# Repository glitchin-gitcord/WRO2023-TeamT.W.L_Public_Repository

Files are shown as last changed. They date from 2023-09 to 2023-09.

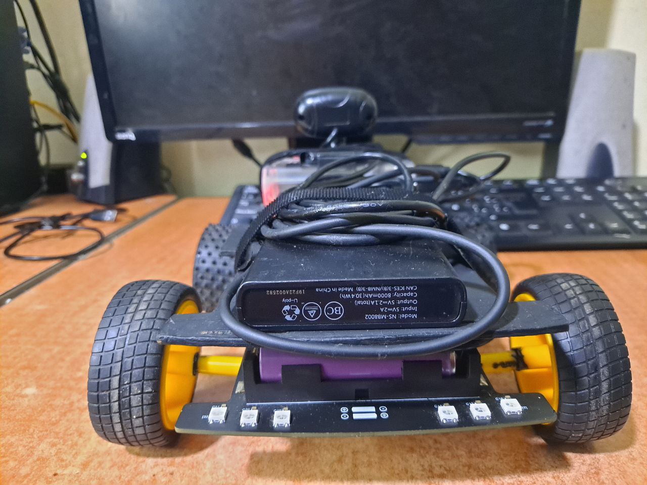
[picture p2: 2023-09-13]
v-photos/back part.jpeg

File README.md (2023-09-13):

Engineering materials
====

This repository contains engineering materials of a self-driven vehicle's model participating in the WRO Future Engineers competition in the season 2023 (Team T.W.L).

## Content

* `t-photos` contains 2 photos of the team (an official one and one funny photo with all team members)
* `v-photos` contains 6 photos of the vehicle (from every side, from top and bottom)
* `video` contains the video.md file with the link to a video where driving demonstration exists
* `schemes` contains one or several schematic diagrams in form of JPEG, PNG or PDF of the electromechanical components illustrating all the elements (electronic components and motors) used in the vehicle and how they connect to each other.
* `src` contains code of control software for all components which were programmed to participate in the competition
* `models` is for the files for models used by 3D printers, laser cutting machines and CNC machines to produce the vehicle elements. If there is nothing to add to this location, the directory can be removed.
* `other` is for other files which can be used to understand how to prepare the vehicle for the competition. It may include documentation how to connect to a SBC/SBM and upload files there, datasets, hardware specifications, communication protocols descriptions etc. If there is nothing to add to this location, the directory can be removed.

## Introduction

_Hello, Here Luis from Team T.W.L., and again I and my colleagues will expand a little in the operational elements present in the robotic solution for this 2023 season._

-------------------------------------------------------------------------------------------------------------------------------------  

_The designed robotic solution model this time consists on a modification of the original robot car we built, leaving only some parts for ease and costs savings. Again, this robot car is powered by ESP-32 and Raspberry Pi 4 and programmed in C++ (ARDUINO IDE) and Python._

_Now, we will expand in the main aspects used and incluided in the robot car's development (**Elements** and **Coding Environments**):_

     Elements

  -   _Motors: The robot has 1 direct current (DC) motor and 1 SG90 servomotor that allow it to move in different directions. Meanwhile the DC motor serves as rear wheel drive, the servomotor gives it the ability to turn left or right. The rear wheel drive motor provides the forward or backward motion of the robot, while the turning motor rotates the front wheels to change the orientation of the robot. By combining these two motions, the robot can move in any direction on a flat surface._  

  -   _ESP-32: Dual-Core SoC Chip (System on a Chip) of low cost and energy that uses a Tensilica Xtensa LX6 microprocessor (both in the one used here, and in its single or dual-core variants). Being an popular alternative to use beacuse of the low energy compsuntion and high processing power. This, along with the Raspberry Pi, being the main elements in the entire robot._

  -   _Raspberry Pi 4: The Raspberry Pi 4 is a single-board development board used for entry-level computing, being released the latest version (Raspberry Pi 4) in June 2019. The board is available in four RAM variants: 1 GB, 2 GB, 4 GB, and 8 GB. Model B (the one we are using) is the most common and comes with a Broadcom BCM2711 processor, which is a 1.5GHz quad-core ARM Cortex-A72 processor. Additionally, it has enhanced USB capability with two USB 2.0 ports and two USB 3.0 ports, enabling up to ten times faster data transfers. It also comes with Gigabit Ethernet connectivity, built-in wireless and Bluetooth._

  _Before, the ESP-32 did all the hard work in the entire robot, but in the tests we noticed that it wouldn't take it, so we looked for alternatives to something that could take all the functions the robot had to handle by itself, so Edilio had the idea to use a Raspberry Pi 4 because of the experience he had investigating about it, so we got one to take at least the camera and color recognition functions, leaving the rest to the ESP-32._

   -   _Ultrasonic board: The robot has an HC-SR04 ultrasonic board that works as a sonar. The HC-SR04 sensor has two transducers: a piezoelectric transmitter and receiver, in addition to the electronics necessary for its operation. The operation of the sensor is as follows: the piezoelectric transmitter emits 8 ultrasonic pulses (40KHz) after receiving the order on the TRIG pin, the sound waves travel in the air and bounce when meeting an object, the bounce sound is detected by the piezoelectric receiver, then the ECHO pin changes to High (5V) for a time equal to the time the wave took from when it was emitted to when it was detected, the time of the ECHO pulse is measured by the microcontroller and thus the distance can be calculated to the object. Sensor performance is not affected by sunlight or black-colored material (although acoustically soft materials such as cloth or wool can be difficult to detect). All of this in a range of 2 to 450 cm._

   -   _Camera: The robot uses an Argom Tech 720p Cam20 Webcam, pretty generic so I can't really expand in detail about it._  

   -   _Power Supply Elements:_
   
   =   _3.7V 18650 Lithium Batteries: The robot, due to its high energy consumption (yeh, still uses a lot of energy) uses this peculiar type of batteries to supply itself with energy. These batteries are rechargeable and have a capacity of between 1500 and 3500 mAh (ours supposedly have 9900 mAh but I highly doubt it). The batteries have a nominal voltage of 3.7V and a maximum voltage of 4.2V. The batteries are connected to the robot through a battery holder that has an on/off switch. The batteries can be charged with a special charger that has a protection circuit against overloads and short circuits._

   =   _Power Bank: Because some SBC didn't want to use the same batteries that everyone else used, here we are. Seriously speaking, for accesibility reasons mostly, we use a Insignia NS-MB8002 Power Bank to supply the Raspberry Pi with energy. It has 2 USB ports, along with a Micro-USB port for charging, with an output voltage of 5V and 2.1A._

    Coding Environments
_The previous time we didn't really expand in this point, but although it is not relevant in which programming environment you're developing this, it is relevant to clarify what the ARDUINO IDE is and why we use it in the development of the robot._

  -   _ARDUINO Integrated Development Environment (C++): The Arduino Integrated Development Environment (IDE) is a cross-platform software (for Windows, macOS, Linux) written in the Java programming language. It is used to write and upload code to Arduino-compatible boards, as well as other boards from different manufacturers with the help of additional cores._

_It can handle C and C++ languages with specific rules for organizing the code. It also provides a software library from the Wiring project that has many common I/O functions. The code written by users only needs two basic functions: one to start the sketch and one to run the main loop. These functions are compiled and linked with a main() function in a loop using the GNU toolchain, which is also part of the IDE. The Arduino IDE uses a program called avrdude to turn the executable code into a text file with hexadecimal encoding that is transferred to the Arduino board by a loader program in the board’s firmware._

Its function related to code would be to control movements (rear wheel drive, turn left or right), based on the information sent by the camera (more info ahead).

  -   _Python: Python Integrated Development Environment (or Python for short) is a high-level interpreted programming language whose philosophy emphasizes the readability of its code, it is used to develop applications of all kinds, for example: Instagram, Netflix, Spotify, Panda3D, among others. It is a multi-paradigm programming language, since it partially supports object orientation, imperative programming and, to a lesser extent, functional programming. It is an interpreted, dynamic and cross-platform language. Created back in late 80s, Python consistently ranks as one of the most popular programming languages._

Its function related to code would be to detect colors and control the camera, and, subsequently, sends orders to the ESP-32 to move based on that information.

-----------------------------------------------------------------------------------------------------------------------------------------

    HOW THE CAMERA WORKS

_The artificial vision algorithms that are used to recognize objects or colors are computer programs that process the images captured by the camera and extract relevant information from them. For example, to recognize colors, We use an algorithm that converts color images to grayscale and then applies a red, green or blue color mask depending on the color we want to detect. Then, we calculate the percentage of pixels of the desired color in the image and compare it with a predefined threshold to determine whether or not there is presence of the color._

    HOW TO COMPILE THE CODE TO THE VEHICLE

_If you already finished the code that you are going to enter to ESP-32, the process of compiling it would be the following:_
- _Connect the ESP-32 to the computer through a Micro-USB cable_
- _Look for the button in the Programming Environment to transfer the code_
- _Wait for it to finish_

  {and well, Python runs natively on the Raspberry Pi, so}

--------------------------------------------------------------------------------------------------------------------------------------

    OBJECTIVE OF THE ROBOTIC SOLUTION.

The objetctive of this robotic solution is to demonstrate the capabilities of a study field such as robotics, kids and adults alike {well, we should serve as enough example to prove that concept ¯\_(ツ)_/¯}.

--------------------------------------------------------------------------------------------------------------------------------------
_Thank You._
======================================================================================================================================

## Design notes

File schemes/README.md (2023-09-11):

Electromechanical diagrams
====

This directory must contain one or several schematic diagrams in form of JPEG, PNG or PDF of the electromechanical components illustrating all the elements (electronic components and motors) used in the vehicle and how they connect to each other.

-------

Hi, Luis here, to quickly clarify what is connected to what:

- The car reads the voltage of the batteries through GPIO32 of ESP32. Because the battery 
voltage is not read frequently, this GPIO is also used to control the WS2812 LED.

The voltage acquisition range of GPIO32 on ESP32 is 0-3.3V, while the car is powered by two 18650 lithium 
batteries, whose voltage is 8.4V when they are fully charged, which exceeds the acquisition range of ESP32. 
Therefore, after passing through the voltage divider circuit composed of R3 and R4, the voltage at A0/WS2812 
will be about 1/4 of the battery voltage, 8.4/4=2.1V, which is within the voltage collection range of GPIO32.

- As can be seen from the figures "Ultrasonic" and "Esp-32", ESP32 uses GPIO12 and GPIO15 to control the 
"Trig" and "Echo" pins of the ultrasonic module.

- About the motors, As can be seen from the figure "motor controller", if we want to control the motor M1, we need to set the 14th and 15th 
channels of the PCA9685.

And as for the servos, channels 0-7 of PCA9685 are used to control servos.

- Although not illustrated correctly, the Raspberry Pi 4 gets its energy from a Power Bank via USB, connects to the Esp32 via USB and uses the Webcam via USB.
------------------------

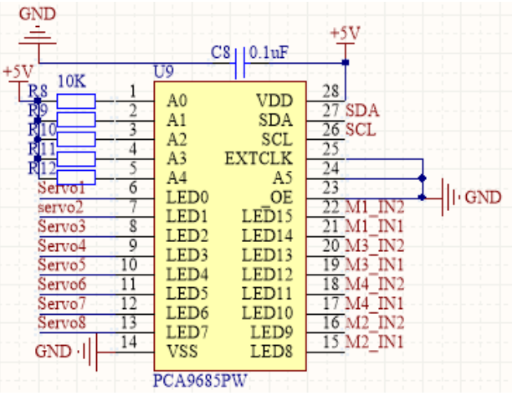
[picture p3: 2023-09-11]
schemes/motor controller.png

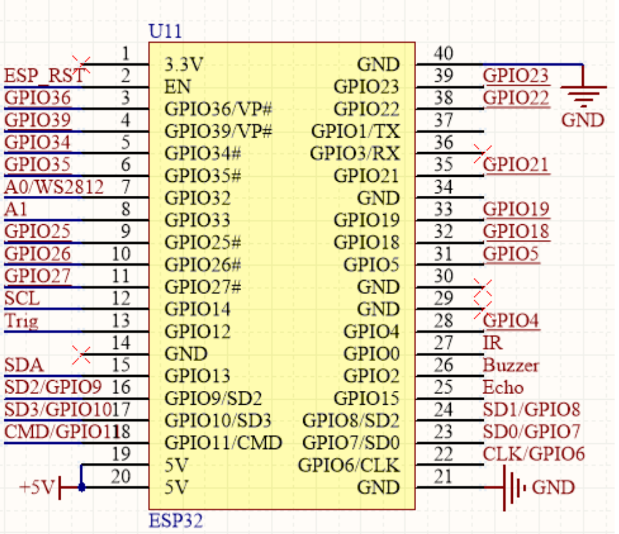
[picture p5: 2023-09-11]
schemes/Esp-32.png

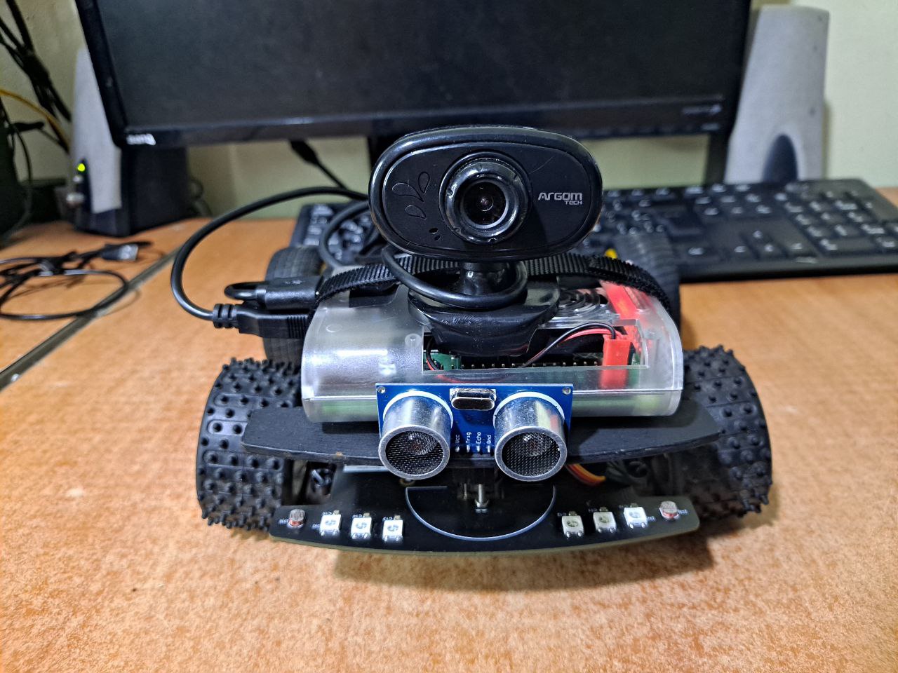
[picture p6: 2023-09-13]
v-photos/front part.jpeg

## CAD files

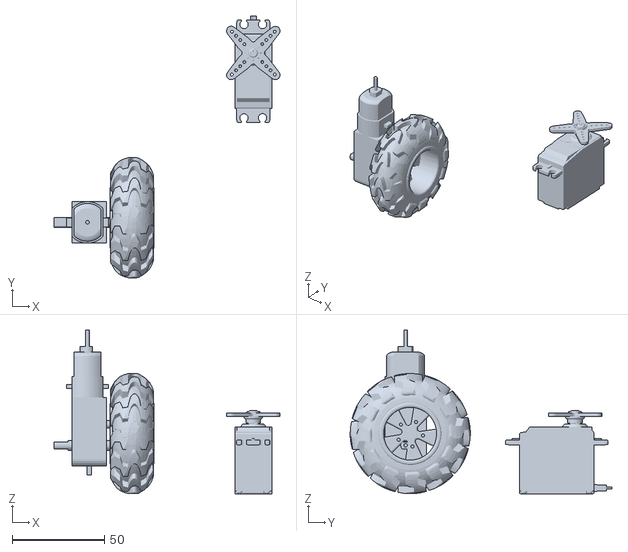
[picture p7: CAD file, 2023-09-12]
models/Copy of TT Motor and Wheel.stl
122.2 x 141.5 x 88.6

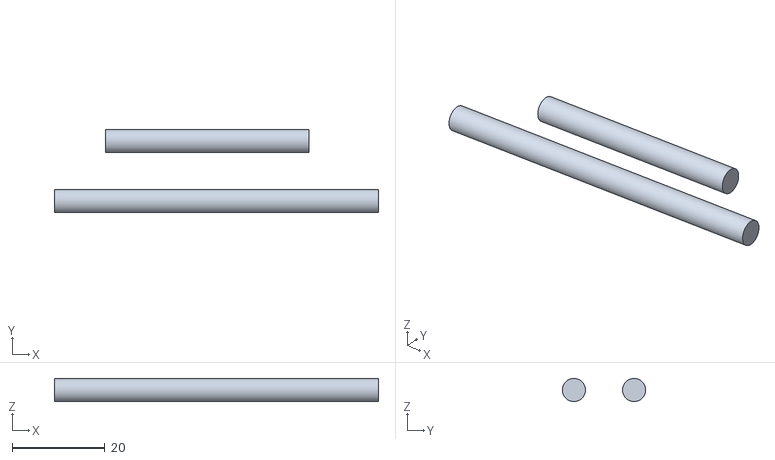
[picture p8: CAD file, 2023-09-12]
models/Magnificent Hillar.stl
70.0 x 18.0 x 5.00

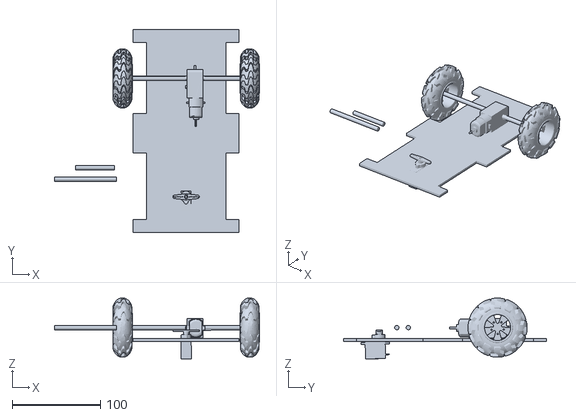
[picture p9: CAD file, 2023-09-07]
models/Swanky Snicket.stl
232.0 x 230.0 x 69.0

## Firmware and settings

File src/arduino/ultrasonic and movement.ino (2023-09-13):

#include <Arduino.h>
#include "Freenove_4WD_Car_For_ESP32.h"

#define OBSTACLE_DISTANCE      30
#define OBSTACLE_DISTANCE_LOW  15
int distance[4];     //Storage of ultrasonic data

String entradaSerial = "";
bool entradaCompleta = false;

void setup() {
  Ultrasonic_Setup();//Initialize the ultrasonic module
  PCA9685_Setup();   //PCA9685 chip initializes
  Serial.begin(115200);
  Serial.println("the bluetooth device is ready to pair");
  Servo_1_Angle(105);//Set servo 1 Angle
}

void loop()
{
  get_distance(1);//Get multiple Angle distance data
  if (distance[1] > OBSTACLE_DISTANCE)//There is no obstacle within 40cm of the front of the car
  {
    if (distance[0] >= distance[2] && distance[2] < OBSTACLE_DISTANCE_LOW) {    //There is an obstacle on the right
      Motor_Move(-1500, -1500, -1500, -1500);
      delay(1200);
      Servo_1_Angle(85);
      Motor_Move(2500, 2500, 2500, 2500);
      delay(1200);
      Servo_1_Angle(105);
    }                                   
    else if (distance[0] < distance[2] && distance[0] < OBSTACLE_DISTANCE_LOW) { //There is an obstacle on the left
      Motor_Move(-1500, -1500, -1500, -1500);
      delay(1200);
      Servo_1_Angle(85);
      Motor_Move(2500, 2500, 2500, 2500);
      delay(1200);
      Servo_1_Angle(105);                      
    }            
    else                                                                      //There are no obstacles around
      Motor_Move(2500, 2500, 2500, 2500);                                                                         
    delay(20);
  }

  else if (distance[1] < OBSTACLE_DISTANCE)  //There is an obstacle ahead
  {
    Motor_Move(0, 0, 0, 0);                  //Stop the car to judge the situation
    get_distance(2);
    if (distance[1] < OBSTACLE_DISTANCE_LOW) //The car got too close to the obstacle
    {
      Motor_Move(-1900, -1900, -1900, -1900);
      }
    else if (distance[0] < distance[2]) {     //There is also an obstacle on the left
      Motor_Move(-1500, -1500, -2000, -2000);
      delay(1200);
      Servo_1_Angle(85);
      Motor_Move(2500, 2500, 2500, 2500);
      delay(1200);
      Motor_Move(0, 0, 0, 0);
      Servo_1_Angle(105); 
      delay(250);         
    }
    else if (distance[0] > distance[2]) {     //There is also an obstacle on the right
     Motor_Move(-1500, -1500, -2000, -2000);
     delay(1200);
     Servo_1_Angle(85);
     Motor_Move(2500, 2500, 2500, 2500);
     delay(1200);
     Motor_Move(0, 0, 0, 0);
     Servo_1_Angle(105); 
     delay(250);         
    }
  }

  if (entradaCompleta) {
    if (entradaSerial == "izq\n") {
      delay(250);
      Serial.print("hola");
      // Mandamos escribir el angulo deseado del giro.
     // delay(3000);
 /*     Servo_1_Angle(85);
      Motor_Move(2200, 2200, 2200, 2200);
      delay(900);
      Servo_1_Angle(105); 
      delay(250); */
      Servo_1_Angle(85);
      Motor_Move(3000, 3000, 3000, 3000);
      delay(900);
      Motor_Move(0, 0, 0, 0);
      Servo_1_Angle(105); 
      delay(250); 
    }
    else if (entradaSerial == "der\n") { 
      delay(250);
      Serial.print("holaa");
      // Mandamos escribir el angulo deseado del giro.
     // delay(3000);
      Servo_1_Angle(125);
      Motor_Move(3000, 3000, 3000, 3000);
      delay(900);
      Servo_1_Angle(105); 
      Motor_Move(0, 0, 0, 0);
      delay(250);
    }
    else { // Cualquier otro dato recibido
      Serial.println("El dato recibido es lol");
    }
    entradaSerial = "";
    entradaCompleta = false;
  }

}

void get_distance(int car_mode)
{
  int add_angle=30;
  if(car_mode==1)
    add_angle=0;
  else
    add_angle=30;
    
  delay(100);
  distance[0] = Get_Sonar();//Get the data on the left

  delay(100);
  distance[1] = Get_Sonar();//Get the data in the middle

  delay(100);
  distance[2] = Get_Sonar();//Get the data on the right

  delay(100);
  distance[1] = Get_Sonar();//Get the data in the middle
}

void serialEvent() {
  while (Serial.available()) {
    // Obtener bytes de entrada:
    char inChar = (char)Serial.read();
    // Agregar al String de entrada:
    entradaSerial += inChar;
    // Para saber si el string está completo, se detendrá al recibir
    // el caracter de retorno de línea ENTER \n
    if (inChar == '\n') {
      entradaCompleta = true;
    }
  }
}

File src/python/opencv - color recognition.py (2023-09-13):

import cv2
import time
import os
import serial
import numpy as np
#import urllib.request
#Definicion de rangos bajos y altos de colores
#x[0] = bajo, x[1] = alto
data = open("/home/mosty/data.txt", "r")
lastseen = data.read()
COM = "/dev/ttyUSB0"
BAUD = 115200
ser = serial.Serial(COM, BAUD)

if "1" in lastseen:
    #Rojo, esto se activa al principio de la ronda si encuentra rojo
    print("el ultimo color que vi fue rojo")
    ser.write(b"der\n")
if "2" in lastseen:
    print("el ultimo color que vi fue verde")
    #Verde, se activa si es verde
    ser.write(b"izq\n")
data.close()



red1 = [(0, 200, 100), (8, 255, 255)]
red2 = [(355, 83, 93), (360, 93, 93)]
green = [(55, 250, 20), (75, 255, 255)]
cap=cv2.VideoCapture(0)
ret,frame=cap.read()
height, width = frame.shape[:2]
print(f"resolucion: {width}x{height}")


#Procesar una nueva imagen
def newImg(framecount, height, width):
    time.sleep(0.025)
    data = 0
    #print("new loop")
    #Toma un frame dependiendo de imgnum debajo de la carpeta frames
    ret,frame=cap.read()
    middle1 = int(height/2-20)
    middle2 = int(height/2+20)
    frame = frame[middle1:middle2,:]
    frame = cv2.flip(frame, 2)
    #img = cv2.flip(frame, -1)


    #convierte la imagen de HSL a HSV
    hsv = cv2.cvtColor(frame, cv2.COLOR_BGR2HSV)
    #Detecta si los colores de la imagen coinciden con los rangos definidos
    redMask1 = cv2.inRange(hsv, red1[0], red1[1])
    redMask2 = cv2.inRange(hsv, red2[0], red2[1])
    greenMask = cv2.inRange(hsv, green[0], green[1])
    #Mezcla redMask1 y redMask2
    redMask = cv2.bitwise_or(redMask1, redMask2)
    #No se que hace esto.
    #Compara la misma imagen entre si pero en la segunda se le alplica la mascara para que solo la zona con la mascara aparezca
    if redMask.max():
        print("rojo encontrado")
        ser.write(b"der\n")
        if framecount >= 40:
            data = 1
            framecount = 0
        
    if greenMask.max():
        print("verde encontrado")
        ser.write(b"izq\n")
        if framecount >= 40:
            data = 2
            framecount = 0
    #Crea una pestana con los frames siendo vistos
    cv2.imshow("cpapu", frame)
    framecount += 1
    return framecount, data
#Main
framecount = 0
while True:
    #Procesa el siguiente frame
    framecount += 1
    framecount, data = newImg(framecount, height, width)
    if data:
        dataw = open("/home/mosty/data.txt", "w")
        dataw.write(str(data))
        dataw.close()
        print(f"written {data}")
    #Al presionar q sale del loop y continua a cerrar las ventanas
    key = cv2.waitKey(5)
    if key == ord('q'):
#        ser.close()
        break 
    if key == ord('r'):
        dataw = open("/home/mosty/data.txt", "w")
        dataw.write("")
        dataw.close()
        break
        
#Cierra todas las ventanas
cap.release()
cv2.destroyAllWindows()
